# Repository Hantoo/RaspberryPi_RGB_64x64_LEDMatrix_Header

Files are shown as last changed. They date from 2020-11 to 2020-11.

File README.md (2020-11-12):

# RaspberryPi_RGB_64x64_LEDMatrix_Header

Simple Raspberry Pi 3/4 header for an RGB 64x64 LED Matrix.  
**Input 5V ONLY!** There is no voltage protection or phase protection. 
For use with LED Matrixes that have A,B,C,D & E selection pins.  
  
Components needed:  
* 2x 74HCT245N  
* 1x Molex , KK 254, 6373, 4 Way, 1 Row, Straight PCB Header, 22-23-2041  
* 1x Molex, KK 254 6373, 2 Way, 1 Row,  Straight PCB Header, 22-23-2021 (**SHOULD BE CHANGED TO CONNECTOR WITH HIGHER LOADING**)  
* 1x 40Pin Raspberry Pi PCB Header  

Connections to raspberry pi follow that of the Adadruit-PWN connection pattern:  
  
    .output_enable = GPIO_BIT(18),  /* Pins 4 and 18 are bound */  
    .clock         = GPIO_BIT(17),  
    .strobe        = GPIO_BIT(21),  
  
    .a             = GPIO_BIT(22),  
    .b             = GPIO_BIT(26),  
    .c             = GPIO_BIT(27),  
    .d             = GPIO_BIT(20),  
    .e             = GPIO_BIT(24),  
  
    .p0_r1         = GPIO_BIT(5),  
    .p0_g1         = GPIO_BIT(13),   
    .p0_b1         = GPIO_BIT(6),  
    .p0_r2         = GPIO_BIT(12),  
    .p0_g2         = GPIO_BIT(16),  
    .p0_b2         = GPIO_BIT(23),  
    
This is the reccomended libary for usage:  
https://github.com/hzeller/rpi-rgb-led-matrix    

Images:  
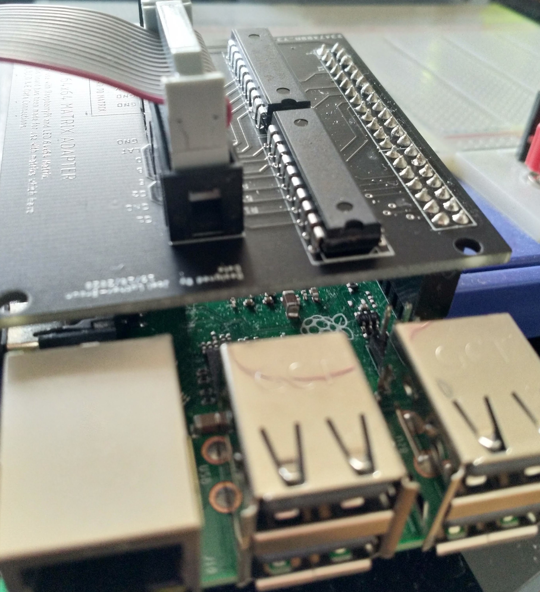
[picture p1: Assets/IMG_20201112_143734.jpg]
Orth View

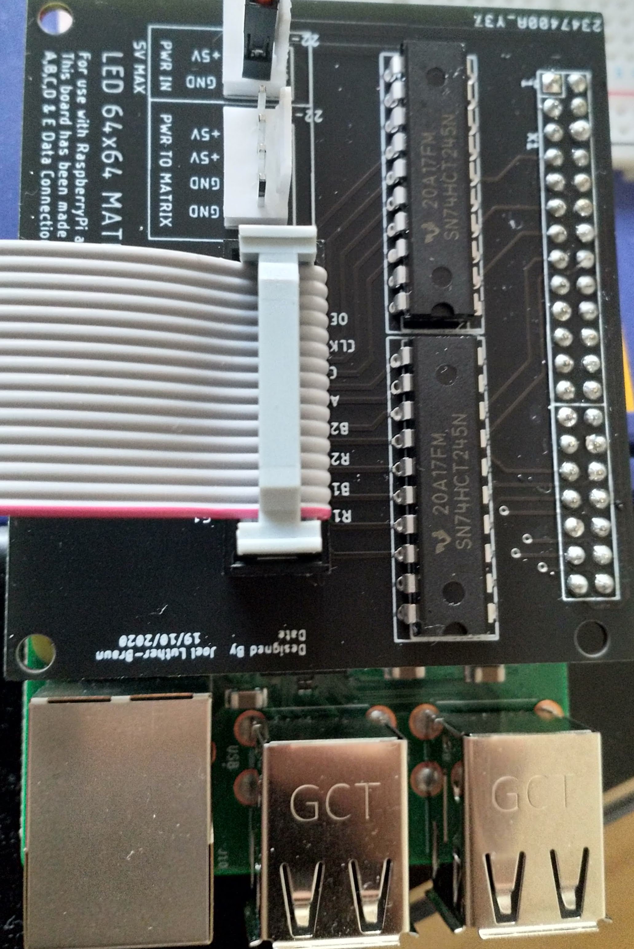
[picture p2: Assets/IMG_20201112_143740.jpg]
Top View

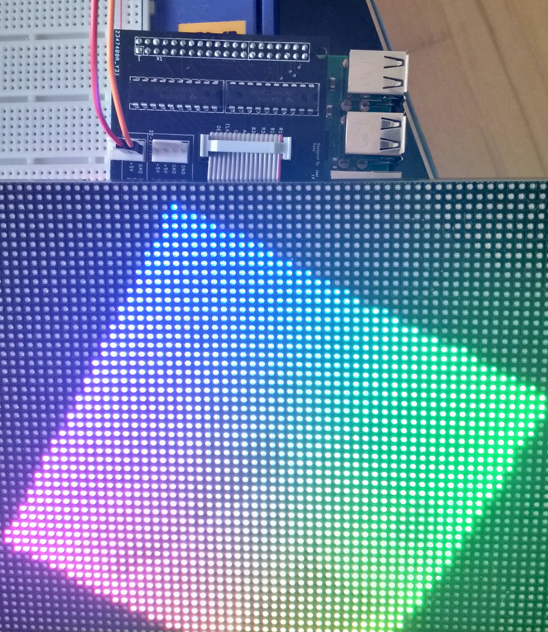
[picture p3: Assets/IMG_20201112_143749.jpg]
Full View


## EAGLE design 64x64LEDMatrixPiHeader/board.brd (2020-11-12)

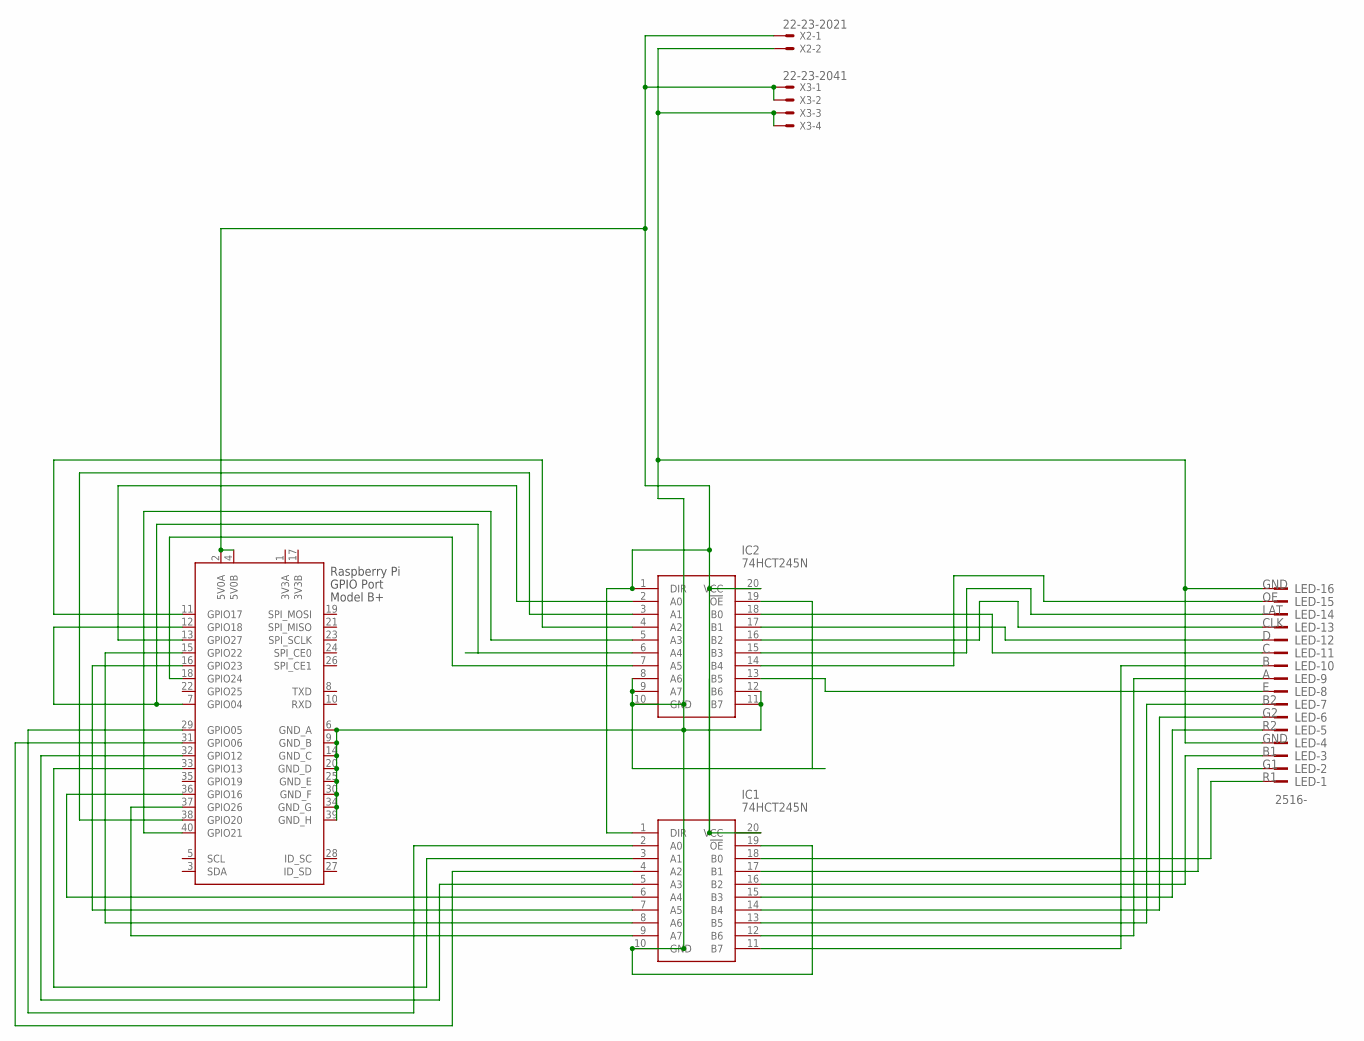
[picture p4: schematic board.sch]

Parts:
IC1, IC2: 74HCT245N; DIP762W53P254L2673H420Q20N
LED: 2516-; PAK100/2500-16
X1: RASPI_GPIO_B+#_PIN; RASPI_GPIO_B+_PIN
X2: 22-23-2021
X3: 22-23-2041

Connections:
3V3A: X1.1 (3V3A)
3V3B: X1.17 (3V3B)
+5V: IC1.1 (DIR), IC1.20 (VCC), IC2.1 (DIR), IC2.20 (VCC), X1.2 (5V0A), X1.4 (5V0B), X2.1, X3.1, X3.2
GND: IC1.10 (GND), IC1.19 (!OE), IC2.8 (A6), IC2.9 (A7), IC2.10 (GND), IC2.11 (B7), IC2.12 (B6), IC2.19 (!OE), LED.4, LED.16, X1.6 (GND_A), X1.9 (GND_B), X1.14 (GND_C), X1.20 (GND_D), X1.25 (GND_E), X1.30 (GND_F), X1.34 (GND_G), X1.39 (GND_H), X2.2, X3.3, X3.4
unnamed: IC1.18 (B0), LED.1
unnamed: IC1.17 (B1), LED.2
unnamed: IC1.16 (B2), LED.3
unnamed: IC1.15 (B3), LED.5
unnamed: IC1.14 (B4), LED.6
unnamed: IC1.13 (B5), LED.7
unnamed: IC1.12 (B6), LED.9
unnamed: IC1.11 (B7), LED.10
unnamed: IC2.2 (A0), X1.13 (GPIO27)
unnamed: IC2.18 (B0), LED.11
unnamed: IC2.17 (B1), LED.12
unnamed: IC2.16 (B2), LED.13
unnamed: IC2.15 (B3), LED.14
unnamed: IC2.14 (B4), LED.15
unnamed: IC1.9 (A7), X1.37 (GPIO26)
unnamed: IC2.6 (A4), X1.7 (GPIO04), X1.12 (GPIO18)
unnamed: IC1.7 (A5), X1.16 (GPIO23)
unnamed: IC1.8 (A6), X1.15 (GPIO22)
unnamed: IC2.5 (A3), X1.40 (GPIO21)
unnamed: IC2.3 (A1), X1.38 (GPIO20)
unnamed: IC2.4 (A2), X1.11 (GPIO17)
unnamed: IC1.6 (A4), X1.36 (GPIO16)
unnamed: IC1.3 (A1), X1.33 (GPIO13)
unnamed: IC1.5 (A3), X1.32 (GPIO12)
unnamed: IC1.2 (A0), X1.29 (GPIO05)
unnamed: IC1.4 (A2), X1.31 (GPIO06)
unnamed: IC2.7 (A5), X1.18 (GPIO24)
unnamed: IC2.13 (B5), LED.8

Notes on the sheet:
GND
LAT
CLK

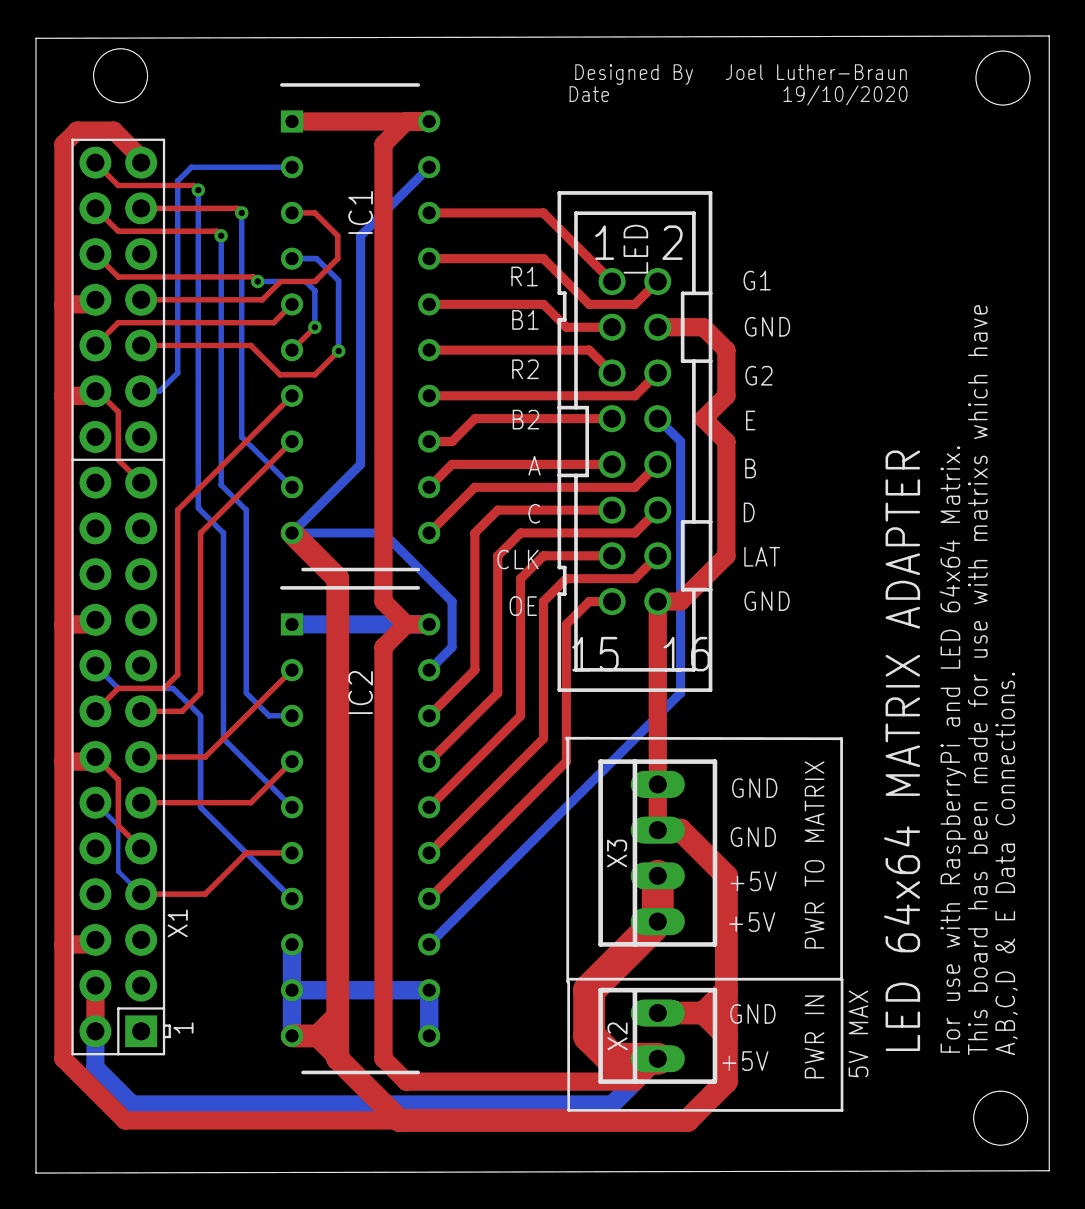
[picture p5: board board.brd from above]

Board: 2 copper layers, 56.3 x 63.2 mm, 6 parts (0 on the bottom side), 30 nets.
